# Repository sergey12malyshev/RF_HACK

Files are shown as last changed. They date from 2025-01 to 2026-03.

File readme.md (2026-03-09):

# RF_HACK

(EN)

A platform for testing wireless transmission and radio interfaces

Currently supports:

- Sub-GHz CC1101 TI transceiver
- GPS module GY-NEO-6M-V2
- 2.4GHz NRF24L01+ (under implementation)

Interaction with the software takes place through the ILI9341 display + xpt2046 touchscreen + encoder or CLI interface

Performs:

- reception with GPS coordinates display;
- transmission and reception in the Sub-GHz range of the test string;
- range scanning mode with spectrum output on the display;
- continuous generation of the test signal in the selected LPD channel (433MHz).

(РУС)

Платформа для тестирования беспроводной передачи и радиоинтерфейсов

На текущий момент поддерживает:

- Sub-GHz приёмопередатчик СС1101 TI
- GPS модуль GY-NEO-6M-V2
- 2.4 ГГц nrf24l01+ (в процессе реализации)

Взаимодействие с ПО происходит через дисплей ILI9341 + тачскрин xpt2046 + энкодер мли CLI.

Осуществляет:

- прием и отображение GPS-координат;
- передачу и прием в Sub-GHz диапазоне тестовой строки;
- режим сканирования диапазона с выводом спектра;
- непрерывную генерацю тестового сигнала в выбранном канале LPD (433 МГц).

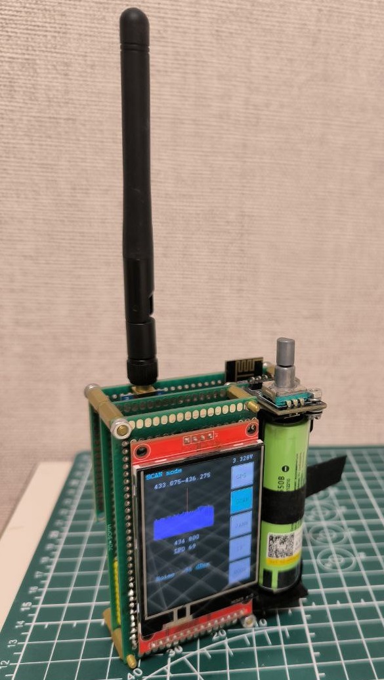
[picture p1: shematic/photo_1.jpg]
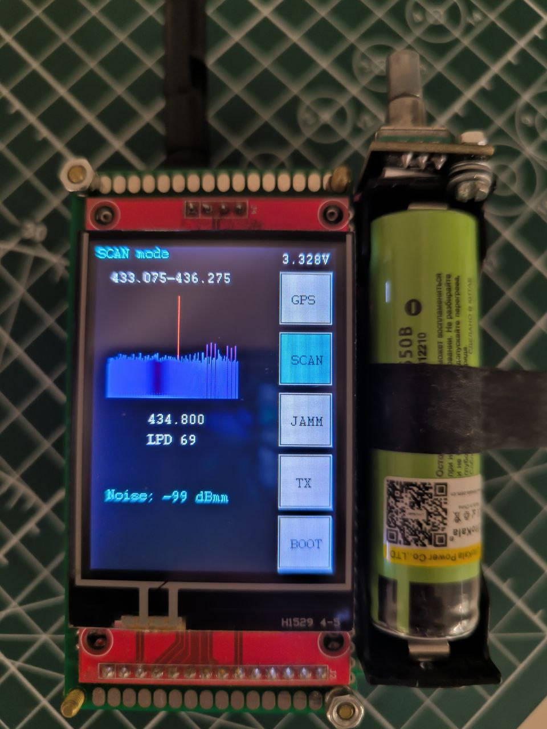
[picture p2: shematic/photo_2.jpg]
   

Video on youtube:

IMAGE ALT TEXT HERE (http://www.youtube.com/watch?v=krAb-4GRXaA)

## MCU
STM32F401CC, High-performance access line, Arm Cortex-M4 core with DSP and FPU, 256 Kbytes of Flash memory, 84 MHz CPU, ART Accelerator

Batch Runner - to run from VSCode

How to enable float support for std withdrawal:
https://stackoverflow.com/questions/54534700/enabling-floating-point-emulation-in-gcc-arm-none-eabi

The frequency of the APB1 (SPI2) bus was reduced four times, otherwise there were problems with the transmission power of CC1101 (the frequency of exchange with CC1101 is no more than 10 Mhz)

## 🛠️ Tools

### Compiler
*GCC* (gcc-arm-none-eabi) version 5.4.1 20160919

Program language: C11 and C++11

#### Setting up the build system in WINDOWS10 

1. Download GNU Arm Embedded Toolchain 
https://developer.arm.com/downloads/-/gnu-rm#:~:text=The%20GNU%20Arm%20Embedded%20Toolchain,Arm%20Cortex%2DR%20processor%20families
or
https://launchpad.net/gcc-arm-embedded/+download

2. Download Windows Build Tools binaries (Make, cp, rm, echo, sh...)
https://github.com/xpack-dev-tools/windows-build-tools-xpack/releases/

3. Add paths to the PATH environment variable in Windows

Detailed article: https://habr.com/ru/articles/673522/

### RTOS
Prototreads AD v1.4

https://dunkels.com/adam/pt/

### Code editor
*VS Code* file Pac-ManGame.code-workspace

## ⚙️ Build 

The build can be started via VSCode Tasks

To make the release project run **makeProject.bat** (OR *make -j* cmd command)

To make the debug project run **makeProjectDebug.bat** (OR *make -j1 debug* cmd command)

To clean the project run **makeClean.bat** (OR *make clean*)

## 📥 Programm firmware
Connect ST-Link V2 to SWD connector. Run **programFlash.bat**

Connect J-Link to SWD connector. Run **programFlash_Jlink.cmd**

## 🔄 Update firmware use system bootloader (DFU Mode)

UART CLI-> BOOT command to launch the system bootloader. Connect to PC via USB Type C. Run **updateFirmware.cmd** or launch STM32CubeProgrammer (select the desired COM-port and download the firmware).

## 🖥️ Command Line Interface

USB-UART 115200 Baud rate 8N1

Terminal configuration file: utils\TERATERM.INI

Enter *help* command

## 🔍 Static code analyzer
Cppcheck 2.10 https://cppcheck.sourceforge.io/

Run **RunStaticAnalysisCODE.cmd**

It is possible to output the analysis result to a file

## 🧰 Hardware
- Black pill STM32F401CC
- CC1101 module
- GY-NEO-6M-V2 GPS module
- 2.8 TFT SPI 240x320 display (ILI9341)
- TP4056 charge module with protection
- Battery 18650 li-ion
- CH340N USB-UART module (Optional for updating firmware via USB Type-C and working with CLI)
- P-MOSFET for power switch

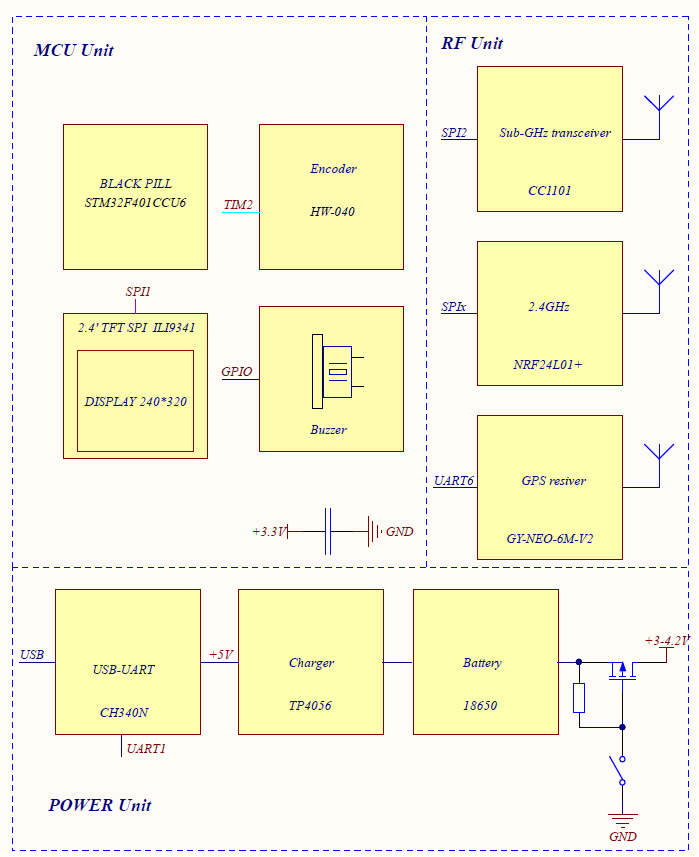
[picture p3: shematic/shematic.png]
 

## 🌿 About repo

Work in the repository is carried out through the Git-flow branching model

Run the **generateRelease.bat** to automatically generate an archive with the software 

## ⚖️⚠️ Legal Compliance / Ответственность

(EN)
This device operates on radio frequencies that may be regulated by local laws and international treaties.  
**It is your responsibility** to ensure that the use of this hardware and software complies with all applicable regulations in your country or region.

Key points to consider:
- **Frequency bands**: Ensure you are operating only in license‑free bands (e.g., LPD, PMR, ISM) or that you hold the necessary amateur radio license.
- **Output power**: Many bands (e.g., LPD 433 MHz) have strict power limits (typically ≤10 mW). Exceeding these limits may be illegal.
- **Spurious emissions**: The device must not cause harmful interference to other services.
- **Antenna restrictions**: Some regulations limit antenna type and gain.
- **Electromagnetic compatibility (EMC)**: The device should not disturb nearby electronic equipment.

The authors and contributors of this project **assume no liability** for any misuse or non‑compliance with local laws. By using this project, you agree that you are solely responsible for its lawful operation.

---

(РУС)
Данное устройство работает на радиочастотах, которые могут регулироваться местными законами и международными соглашениями.  
**Вы несёте полную ответственность** за то, чтобы использование этого оборудования и программного обеспечения соответствовало всем применимым нормам в вашей стране или регионе.

На что следует обратить особое внимание:
- **Частотные диапазоны**: Убедитесь, что вы работаете только в безлицензионных диапазонах и каналах (например, LPD, PMR, ISM) или имеете соответствующую радиолюбительскую категорию.
- **Выходная мощность**: Для многих диапазонов (например, LPD 433 МГц) установлены жёсткие ограничения по мощности (обычно ≤10 мВт). Превышение этих лимитов может быть незаконным.
- **Побочные излучения**: Устройство не должно создавать помех другим службам.
- **Ограничения на антенны**: Некоторые нормативы ограничивают тип и коэффициент усиления антенны.
- **Электромагнитная совместимость (ЭМС)**: Устройство не должно создавать помех близлежащей электронной аппаратуре.

Авторы и участники этого проекта **не несут ответственности** за любое неправомерное использование или несоблюдение местных законов. Используя этот проект, вы соглашаетесь, что только вы отвечаете за его законную эксплуатацию.

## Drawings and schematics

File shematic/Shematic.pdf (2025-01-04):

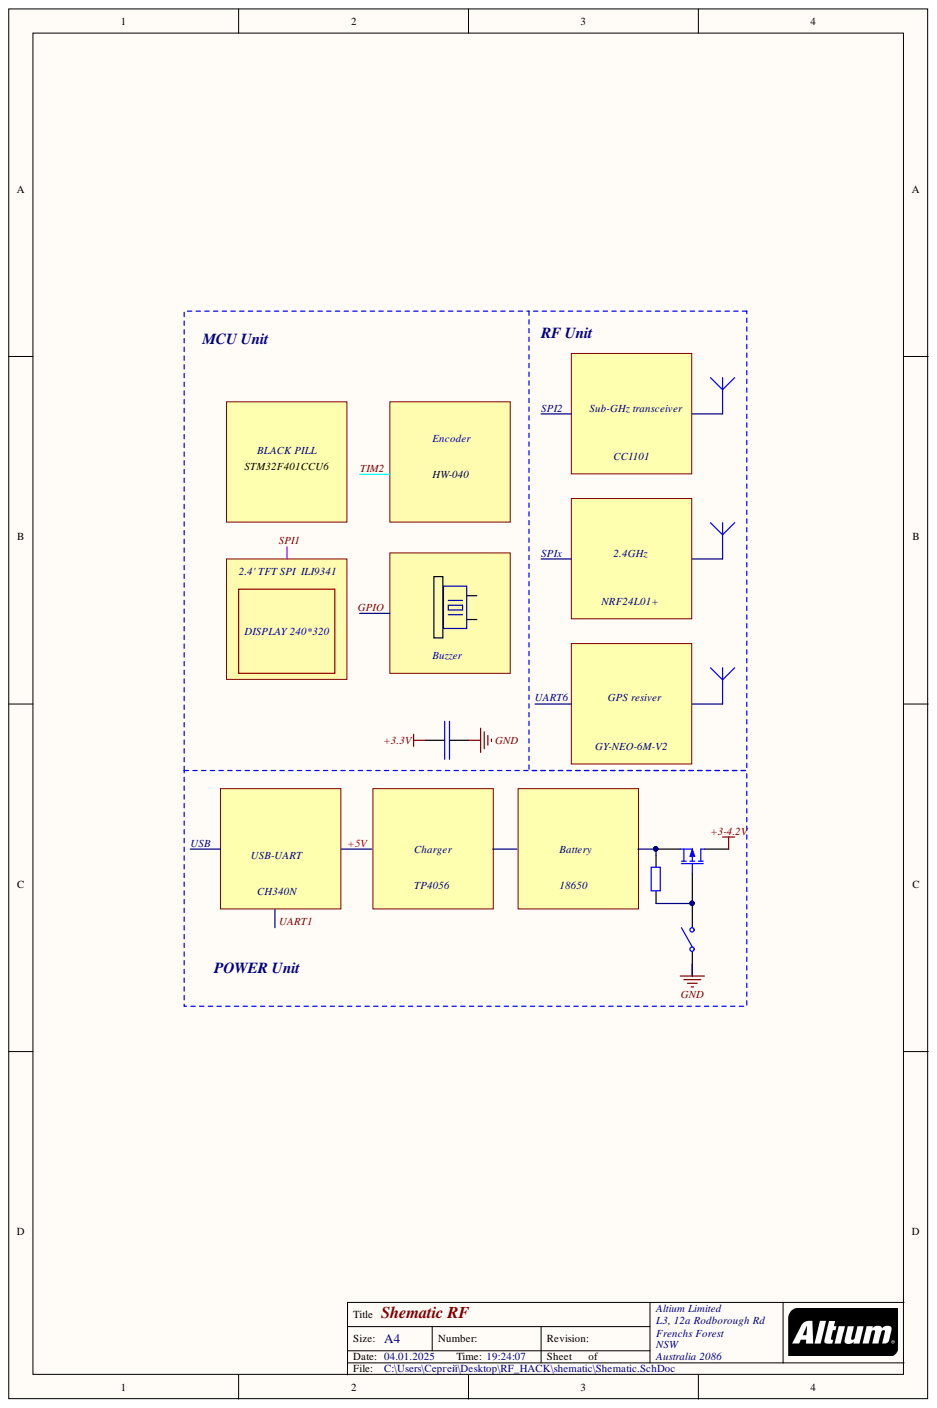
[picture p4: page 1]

Title Shematic RF | Altium Limited L3, 12a Rodborough Rd Frenchs Forest NSW Australia 2086

Size: A4 | Number: | Revision:

Date: 04.01.2025 Time: 19:24:07 | | Sheet of
File: C:\Users\Сергей\Desktop\RF_HACK\shematic\Shematic.SchDoc

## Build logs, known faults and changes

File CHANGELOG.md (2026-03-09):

History of changes
====

# 0.4.0
- Add j-link programm script
- Refactoring CC1101 driver
- New sound control algorithm
- Update CLI-Driver

# 0.3.2
- Updating the FIFO queue library
- Refactoring the CLI module  
- Updating the project structure: separation of user files and peripheral files generated by CubeMX
- Adding C++ files to the project Build

# 0.3.1
- Changed the software version project

# 0.3.0 
- Refactoring the project, without changing the functionality
- Add Vscode tasks
- Revision of the software release archive generation script

# 0.2.0

# 0.1.0

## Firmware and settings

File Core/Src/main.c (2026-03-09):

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
/* Includes ------------------------------------------------------------------*/
#include "main.h"
#include "adc.h"
#include "dma.h"
#include "iwdg.h"
#include "spi.h"
#include "tim.h"
#include "usart.h"
#include "gpio.h"

/* USER CODE BEGIN Includes */
#include <stdlib.h>
#include <stdio.h>
#include <string.h>
#include <stdbool.h>


#include "workStates.h"
#include "configFile.h"

#include "sheduler.h"

#include "display.h"
#include "ili9341.h"
#include "xpt2046.h"
#include "calibrate_touch.h"
#include "demo.h"
#include "displayInit.h"

#include "button_Thread.h"
#include "gps_Thread.h"

#include "runBootloader.h"
#include "buzzer_driver.h"

#include "gps.h"
#include "cc1101.h"

#include "cli_driver.h"
#include "cli_thread.h"

#include "encoderDriver.h"
#include "application_Thread.h"
#include "button_Thread.h"
#include "subGHz_RX_Thread.h"
#include "subGHz_TX_Thread.h"
#include "spectrumScan_Thread.h"
#include "jammer_Thread.h"
#include "configFile.h"

#include "test.h"

/* USER CODE END Includes */

/* USER CODE BEGIN PM */
#define GCC_VERSION ((__GNUC__ * 100) + (__GNUC_MINOR__ * 10) + ( __GNUC_PATCHLEVEL__ ))

// Firmware builds require at least GCC 5.4.1
#if (GCC_VERSION < 541)
	#error "GCC compiler >= 5.4.1 required"
  #pragma message("GCC is " STR(__GNUC__)"."STR(__GNUC_MINOR__)"."STR(__GNUC_PATCHLEVEL__))
#endif
/* USER CODE END PM */


void SystemClock_Config(void);
/* USER CODE BEGIN 0 */

void checkResetSourse(void)
{
  if (__HAL_RCC_GET_FLAG(RCC_FLAG_PORRST) != RESET)
  {    
    DEBUG_PRINT(CLI_SYS"PORRST"CLI_NEW_LINE);
  }   
  else if (__HAL_RCC_GET_FLAG(RCC_FLAG_SFTRST) != RESET)    
  {
    DEBUG_PRINT(CLI_SYS"SFTRST"CLI_NEW_LINE);
  } 
  else if (__HAL_RCC_GET_FLAG(RCC_FLAG_IWDGRST) != RESET)    
  {
    DEBUG_PRINT(CLI_SYS"IWDGRST"CLI_NEW_LINE);
  }  
  else if (__HAL_RCC_GET_FLAG(RCC_FLAG_PINRST) != RESET)    
  {
    DEBUG_PRINT(CLI_SYS"PINRST"CLI_NEW_LINE);
  }
  __HAL_RCC_CLEAR_RESET_FLAGS();
}

static void stm32_cacheEnable(void)
{
#if (INSTRUCTION_CACHE_ENABLE != 0U) /* Enable caching instructions */
  ((FLASH_TypeDef *) ((0x40000000UL + 0x00020000UL) + 0x3C00UL))->ACR |= (0x1UL << (9U));
#endif

#if (DATA_CACHE_ENABLE != 0U) /* Enabling data caching */
  ((FLASH_TypeDef *) ((0x40000000UL + 0x00020000UL) + 0x3C00UL))->ACR |= (0x1UL << (10U));
#endif

#if (PREFETCH_ENABLE != 0U) /* Enabling the instruction prefetch system */
  ((FLASH_TypeDef *) ((0x40000000UL + 0x00020000UL) + 0x3C00UL))->ACR |= (0x1UL << (8U));
#endif
}
/* USER CODE END 0 */

/**
  * @brief  The application entry point.
  * @retval int
  */
int main(void)
{
  /* USER CODE BEGIN 1 */
  stm32_cacheEnable();
  /* USER CODE END 1 */

  /* MCU Configuration--------------------------------------------------------*/

  /* Reset of all peripherals, Initializes the Flash interface and the Systick. */
  HAL_Init();

  /* Configure the system clock */
  SystemClock_Config();

  /* USER CODE BEGIN SysInit */
  
  SysTick_Config(SystemCoreClock/1000); //Setting up the system timer (interrupts 1000 times per second)
  /* USER CODE END SysInit */

  /* Initialize all configured peripherals */
  MX_GPIO_Init();
  MX_DMA_Init();
  MX_SPI1_Init();
  MX_TIM3_Init();
  MX_USART1_UART_Init();
  MX_USART6_UART_Init();
  MX_SPI2_Init();
  MX_ADC1_Init();
  MX_IWDG_Init();
  MX_TIM2_Init();
  /* USER CODE BEGIN 2 */

#ifndef  LCD_DYNAMIC_MEM
  LCD_Handler lcd1;
#endif

  LCD = LCD_DisplayAdd(LCD,
#ifndef  LCD_DYNAMIC_MEM
            &lcd1,
#endif
             240,
             320,
             ILI9341_CONTROLLER_WIDTH,
             ILI9341_CONTROLLER_HEIGHT,
             //Setting the width and height offset for non-standard or defective displays:
             0,    //offset in width of the display matrix
             0,    //height offset of the display matrix
             PAGE_ORIENTATION_PORTRAIT,
             ILI9341_Init,
             ILI9341_SetWindow,
             ILI9341_SleepIn,
             ILI9341_SleepOut,
             displayInit_getSpiPortSettings(),
             LCD_DATA_16BIT_BUS,
             bkl_data);

  lcd = LCD;     //Pointer to the first display in the list
  LCD_Init(lcd);
  LCD_Fill(lcd, COLOR_RED);

  XPT2046_InitTouch(&touch1, 20, &cnt_touch);   //initializing the handler XPT2046

#if !CALIBRATE_EN
  touch1.coef = *displayInit_getCalibrationCoefficient();
#else
  calibrateTouchEnable();
#endif

#if RUN_LCD_DEMO
  LCD_Fill(lcd, COLOR_WHITE);
  Draw_TouchPenDemo(&touch1, lcd);
  RoadCircleDemo(&touch1, lcd);
#endif
  LCD_Fill(lcd, COLOR_BLACK);
  /* USER CODE END 2 */

  /* Infinite loop */
  /* USER CODE BEGIN WHILE */

#if CLI_ENABLE
  cli_init();
#endif // CLI_ENABLE

  debugPrintf("C++ test: %s"CLI_NEW_LINE, test_cpp_function() ? "true" : "false");

  buzzer_init(BUZZER_GPIO_Port, BUZZER_Pin);
  buzzer_soundOn(BUZZ_SOUND_TEST);
  debugPrintf("Buzzer test..."CLI_NEW_LINE);

  adc_enable();

  debugPrintf("CC1101 init..."CLI_NEW_LINE);
  LCD_WriteString(lcd, 5, 25, "CC1101 int...",
            &Font_8x13, COLOR_WHITE, COLOR_BLACK, LCD_SYMBOL_PRINT_FAST);

#if CC1101_CUSTOM_OLD_CONFIG
  CC1101_setCarrierFreq(CFREQ_433);
  CC1101_setDevAddress(1); 
#endif


  bool error_state = CC1101_init(&hspi2, 
                NSS_CS_GPIO_Port, NSS_CS_Pin,      // CS pin
                GPIOB, LL_GPIO_PIN_14,             // MISO pin
                GPIOB, LL_GPIO_PIN_12);            // GDO pin

  if (!error_state)
  {
    debugPrintf(CLI_OK"CC1101 init pass"CLI_NEW_LINE);
  }
  else
  {
    LCD_WriteString(lcd, 5, 55, "CC1101 not found!",
            &Font_8x13, COLOR_WHITE, COLOR_RED, LCD_SYMBOL_PRINT_FAST);
    while (1)
    {
      IWDG_reload();
    }
  }

  encoder_init();
  
    /* USER CODE END WHILE */

    /* USER CODE BEGIN 3 */
    
  scheduler_run();

  /* USER CODE END 3 */
}

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
/**
  * @brief  Period elapsed callback in non blocking mode
  * @note   This function is called  when TIM1 interrupt took place, inside
  * HAL_TIM_IRQHandler(). It makes a direct call to HAL_IncTick() to increment
  * a global variable "uwTick" used as application time base.
  * @param  htim : TIM handle
  * @retval None
  */
void HAL_TIM_PeriodElapsedCallback(TIM_HandleTypeDef *htim)
{
  if (htim->Instance == TIM1) {
    HAL_IncTick();
  }
}

/**
  * @brief  This function is executed in case of error occurrence.
  * @retval None
  */
void Error_Handler(void)
{
  /* USER CODE BEGIN Error_Handler_Debug */
  /* User can add his own implementation to report the HAL error return state */
  __disable_irq();

  debugPrintf("HAL_ERROR!\r\n");
  while (1)
  {
  }
  /* USER CODE END Error_Handler_Debug */
}

#ifdef  USE_FULL_ASSERT
/**
  * @brief  Reports the name of the source file and the source line number
  *         where the assert_param error has occurred.
  * @param  file: pointer to the source file name
  * @param  line: assert_param error line source number
  * @retval None
  */
void assert_failed(uint8_t *file, uint32_t line)
{
  /* USER CODE BEGIN 6 */
  /* User can add his own implementation to report the file name and line number,
     ex: printf("Wrong parameters value: file %s on line %d\r\n", file, line) */
  debugPrintf("Wrong parameters value: file %s on line %d\r\n", file, line);
  while(1);
  /* USER CODE END 6 */
}
#endif /* USE_FULL_ASSERT */

/************************ (C) COPYRIGHT STMicroelectronics *****END OF FILE****/

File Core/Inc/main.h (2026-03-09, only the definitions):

#define RED_LED_Pin LL_GPIO_PIN_13
#define RED_LED_GPIO_Port GPIOC
#define LCD_DC_Pin LL_GPIO_PIN_2
#define LCD_DC_GPIO_Port GPIOA
#define LCD_RESET_Pin LL_GPIO_PIN_3
#define LCD_RESET_GPIO_Port GPIOA
#define LCD_CS_Pin LL_GPIO_PIN_4
#define LCD_CS_GPIO_Port GPIOA
#define LCD_SCK_Pin LL_GPIO_PIN_5
#define LCD_SCK_GPIO_Port GPIOA
#define LCD_LED_Pin LL_GPIO_PIN_6
#define LCD_LED_GPIO_Port GPIOA
#define LCD_SDI_Pin LL_GPIO_PIN_7
#define LCD_SDI_GPIO_Port GPIOA
#define T_IRQ_Pin LL_GPIO_PIN_0
#define T_IRQ_GPIO_Port GPIOB
#define T_IRQ_EXTI_IRQn EXTI0_IRQn
#define T_CS_Pin LL_GPIO_PIN_1
#define T_CS_GPIO_Port GPIOB
#define CC_GDO_Pin LL_GPIO_PIN_12
#define CC_GDO_GPIO_Port GPIOB
#define CC_GDO_EXTI_IRQn EXTI15_10_IRQn
#define NSS_CS_Pin LL_GPIO_PIN_13
#define NSS_CS_GPIO_Port GPIOB
#define BUZZER_Pin LL_GPIO_PIN_15
#define BUZZER_GPIO_Port GPIOA
#define T_OUT_Pin LL_GPIO_PIN_4
#define T_OUT_GPIO_Port GPIOB
#define ENCODER_SW_Pin LL_GPIO_PIN_8
#define ENCODER_SW_GPIO_Port GPIOB
#define ENCODER_SW_EXTI_IRQn EXTI9_5_IRQn
#define SOFTWARE_VERSION_MAJOR  0
#define SOFTWARE_VERSION_MINOR  4
#define SOFTWARE_VERSION_PATCH  0
#define __UNUSED __attribute__((unused))

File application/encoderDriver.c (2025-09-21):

#include <stdio.h>
#include <ctype.h>
#include <string.h>
#include <stdbool.h>
#include <stdarg.h>

#include "main.h"
#include "encoderDriver.h"
#include "cli_driver.h"
#include "tim.h"


static bool encoderSwitch;
static bool encoderSwitchIRQ;
static uint32_t encoderTimeSwitch;

static int32_t currCounter;

bool encoder_getStateSwitch(void)
{
  bool rc = false;

  if (encoderSwitch)
  {
    rc = true;
    encoderSwitch = false;
  }

  return rc;
}

void encoder_setStateSwitch(bool const s, uint32_t time)
{
  encoderSwitchIRQ = s;
  encoderTimeSwitch = time;
}

int32_t encoder_getRotaryNum(void)
{
  return currCounter;
}

void encoder_setRotaryNum(int32_t n)
{
  __HAL_TIM_SET_COUNTER(&htim2, 32767 - n);
  currCounter = n;
}

void encoder_init(void)
{
  HAL_TIM_Encoder_Start(&htim2, TIM_CHANNEL_ALL);
  encoder_setRotaryNum(0);
  encoderSwitch = false;
}


int32_t prevCounter = 0;

void encoder_process(void) 
{
  currCounter = __HAL_TIM_GET_COUNTER(&htim2);

  currCounter = 32767 - ((currCounter-1) & 0xFFFF);

  if (currCounter != prevCounter) 
  {
#if 0
    debugPrintf("%d"CLI_NEW_LINE, currCounter);
#endif
    prevCounter = currCounter;
  }
  
   // https://istarik.ru/blog/stm32/148.html
  if (encoderSwitchIRQ && (HAL_GetTick() - encoderTimeSwitch) > 200)
  {
    encoderSwitch = true;
    encoderSwitchIRQ = false;
    LL_EXTI_ClearFlag_0_31(LL_EXTI_LINE_8);
    NVIC_EnableIRQ(EXTI9_5_IRQn);
  }
}

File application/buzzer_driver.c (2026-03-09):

#include <stdbool.h>
#include <stdint.h>

#include "buzzer_driver.h"
#include "main.h"

#define LC_INCLUDE "lc-addrlabels.h"
#include "pt.h"

#include "time.h"

/*
* Buzzer driver
* 
*/

static GPIO_TypeDef *buzzer_port = NULL;
static uint32_t buzzer_pin;

static bool buzzer_sound_on;
static uint32_t buzzer_timeout = 5;

void buzzer_soundOn(uint32_t time)
{
  if (time == 0)
  {
    return;
  }
  buzzer_sound_on = true;
  buzzer_timeout = time;
}

static void buzzer_enable(void)
{
  LL_GPIO_SetOutputPin(buzzer_port, buzzer_pin);
}

static void buzzer_disable(void)
{
  LL_GPIO_ResetOutputPin(buzzer_port, buzzer_pin);
  buzzer_sound_on = false;
}

bool buzzer_init(GPIO_TypeDef *GPIOx, uint32_t PinMask)
{
  if (GPIOx == NULL)
  {
    return true;
  }

  buzzer_port = GPIOx;
  buzzer_pin = PinMask;

  return false;
}



/*
 * Protothread Buzzer_Thread
 *
 * Creating and processing sound
 */

PT_THREAD(Buzzer_Thread(struct pt *pt))
{
  static uint32_t timer_buzzer;

  PT_BEGIN(pt);

  PT_DELAY_MS(pt, &timer_buzzer, timer_buzzer);

  while (true)
  {
    PT_WAIT_UNTIL(pt, buzzer_sound_on);

    buzzer_enable();
    PT_DELAY_MS(pt, &timer_buzzer, buzzer_timeout);
    buzzer_disable();

    PT_YIELD(pt);
  }

  PT_END(pt);
}

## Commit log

2024-06-09 Add toggle led
2024-06-09 Test uart output
2024-06-12 Добавление FreeRTOS
2024-06-12 Процесс добавлени CLI
2024-06-12 Оптимизация и устранение предупреждений
2024-06-13 Добавляю скрипт обновления по uart
2024-06-15 Добавление работы с дисплеем
2024-06-15 Рефакторинг, заменяем табы на прбелы
2024-06-16 Вынощу периферию в отдельеый файл
2024-06-16 Добавление CLI
2024-06-16 Тест
2024-06-16 add heartbeat led
2024-06-16 Увеличил размер стека на основную задачу, иначе было мало для sprintf
2024-06-20 Процесс добавления GPS
2024-06-24 Добавил комманды компилятору для активации работы со float std-вывода
2024-06-24 Доработка библиотеки GPS (иначе были ошибки чтения)
2024-06-26 Фиксирую изменения
2024-06-26 Временно переходим на протопотоки
2024-06-27 рабочая версия
2024-09-20 Вырезал freertos
2024-09-20 Добавляем библиотеку протопотоков
2024-09-20 Рефакторинг
2024-09-23 Добавление драйвера работы с CC1101
2024-09-23 Выводим принятые данные
2024-09-23 передавал указатель не на static переменную
2024-09-23 Реализация обработки кнопки тачскрином
2024-09-23 Добавление протопотока передачи Теперь нажатие кнопки TX запускает передачу
2024-09-24 update button
2024-09-24 осталась проблема с передачей
2024-09-24 Реализация сканера частот
2024-09-27 Добавление отладочной сборки
2024-09-27 Добавление скрипта запуска статического анализатора кода
2024-09-27 Add module buttonDisplay
2024-09-27 Add scann button
2024-09-27 Выделение спектроанализатора в отдельный поток
2024-09-27 Реализация автомата состояний
2024-09-27 Возвращаю конфиг обратно
2024-09-27 Частоту шины APB1 снизил в два раза, иначе были проблемы с передачей CC1101 (снижалась мощность передачи)
2024-09-30 Переделка драйвера СС1101 под LL lib
2024-09-30 При сканировании запрещаем прерывания по GDO
2024-09-30 Добавление переинициализации модуля при переходе в TX или RX (после режима сканирования)
2024-10-23 Снизил тактирование шины APB1 в два раза. Теперь передача на СС1101 проходит стабильно
2024-10-23 Устранение предупреждений компилятора
2024-10-23 Доработка коммандных файлов
2024-10-23 Добавил сообщение о инициализации CC1101, на случай отсутствия модуля
2024-10-23 Выделение логики управления автоматом в отдельный файл
2024-10-23 Сканируем LPD и PMR
2024-10-23 Рефакторинг проекта
2024-10-23 Уменьшил размер стека. Установил размер кучи равным 0 т.к. нет динамического выделения памяти
2024-10-23 Добавление возможности запуска встроенного бутлоадера
2024-10-23 Считаем ошибки приёма
2024-10-24 Добавление автогенерации выходного архива
2024-10-24 Добавил версионирование
2024-10-24 Выводим источник сброса
2024-10-26 Добавление измерения напряжения питания
2024-10-26 Bootload button add
2024-10-26 Добавление генерации случайной посылки
2024-10-26 Базовая частота и частота передачи имеют смещение
2024-10-26 исправил форматирование при выводе напряжения
2024-10-28 Доработка автомата
2024-10-29 новый поток gps_Thread.c добавлено определение уровня шумов
2024-10-29 Попытка добавить водопад
2024-10-30 Добавление защиты от переполнения буфера печати
2024-11-01 Непрерывная передача jamm
2024-11-01 Добавляем задержку между пакетами
2024-11-03 Рефакторинг процедуры передачи
2024-11-03 Перестраиваем работу под прерывание
2024-11-03 Перевод на прерывание GDO0
2024-11-03 Оптимизация
2024-11-03 Доработка алгоритма приёма
2024-11-03 update driver cc1101
2024-11-03 Решение проблемы с ошибками приёма - в функцию приёма приходило рандомное значение неинициализированой переменной
2024-11-03 GDO0 flag to driver
2024-11-04 Добавляем проверку наличия CC1101
2024-11-04 Решение проблемы с зависанием спектра
2024-11-10 Add encoder driver
2024-11-10 Добавляем курсор на спектр
2024-11-11 Добавляем файл с основными частотами
2024-11-11 Добавляем отображение канала LPD
2024-11-13 Рефакторинг драйвера СС1101 Добавление нового функционала
2024-11-13 Refactoring driver
2024-11-13 Add driver of encoder switch
2024-11-13 доработка
2024-11-14 Рефакторинг названий
2024-11-14 Добавление конфиг-файла
2024-11-14 Рефакторинг модуля GPS
2024-11-14 Рефакторинг драйвера gps
2024-11-14 Добавление ограничения для энкодера
2024-11-14 Добавление счётчика для защиты от дребезга при нажатии тача
2024-11-15 удаляем лишнее
2024-11-15 Добавление возможности отключить CLI
2024-11-16 add shematic
    [RF_HACK_shematic.SchDoc]
2024-11-17 add buzzer driver
2024-11-17 add average filter
2024-11-17 average voltage show
2025-01-04 add battery_driver
2025-09-20 reafactoring adc.c
2025-09-20 refactoring battery_driver.c and button_Thread.c
2025-09-21 Fixed the erroneous use of HAL and LL libraries simultaneously.
    [cc1101.c]
2026-01-03 move files CC1101 driver
2026-01-05 Moving the POWER logic into a separate cpp module
2026-01-05 update cli command ADC
2026-02-01 Refactoring CC1101 driver
2026-02-01 refactoring driver CC1101
2026-03-06 Setting up SPI ports by calling a function
2026-03-06 Update CLI-Driver
2026-03-07 Highlighting the function of switching to transmission mode
2026-03-07 refactoring button lcd thread

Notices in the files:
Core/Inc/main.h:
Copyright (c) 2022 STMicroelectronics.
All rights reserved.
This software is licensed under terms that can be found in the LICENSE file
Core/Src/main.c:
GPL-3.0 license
